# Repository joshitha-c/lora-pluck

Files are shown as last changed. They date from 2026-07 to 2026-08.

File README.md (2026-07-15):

# LoRa RP2040 Development Board

A custom-designed LoRa development board built in **KiCad**, combining the powerful **Raspberry Pi RP2040** microcontroller with the **Semtech SX1262 LoRa transceiver**. The board is designed for long-range wireless communication, rapid prototyping, IoT applications, and embedded systems development.
This development board is intended for long-range wireless communication and embedded IoT applications. The RP2040 acts as the main controller while the SX1262 provides LoRa connectivity for transmitting and receiving data over long distances.
---

## Features

- RP2040 dual-core ARM Cortex-M0+ microcontroller
- SX1262 LoRa transceiver (Sub-GHz communication)
- USB Type-C interface for programming and power
- External QSPI Flash memory
- 12 MHz crystal for RP2040
- 32 MHz crystal for SX1262
- RF matching network
- Antenna connector
- Reset and Boot buttons
- On-board voltage regulation
- Proper decoupling capacitors for stable operation
- Designed entirely in KiCad

---

## Main Components

| Component | Description |
|---|---|
| RP2040 | Main Microcontroller |
| SX1262 | LoRa Transceiver |
| W25Q Series Flash | External QSPI Flash Memory |
| USB-C Connector | Programming & Power |
| 12 MHz Crystal | RP2040 Clock |
| 32 MHz Crystal | SX1262 Clock |
| RF Matching Network | Impedance Matching |
| Antenna Connector | RF Output |

---

## Future Improvements

- OLED display support
- GPS module
- Battery charging circuit
- Li-ion battery connector
## Tools Used

- KiCad

schematic

pcb


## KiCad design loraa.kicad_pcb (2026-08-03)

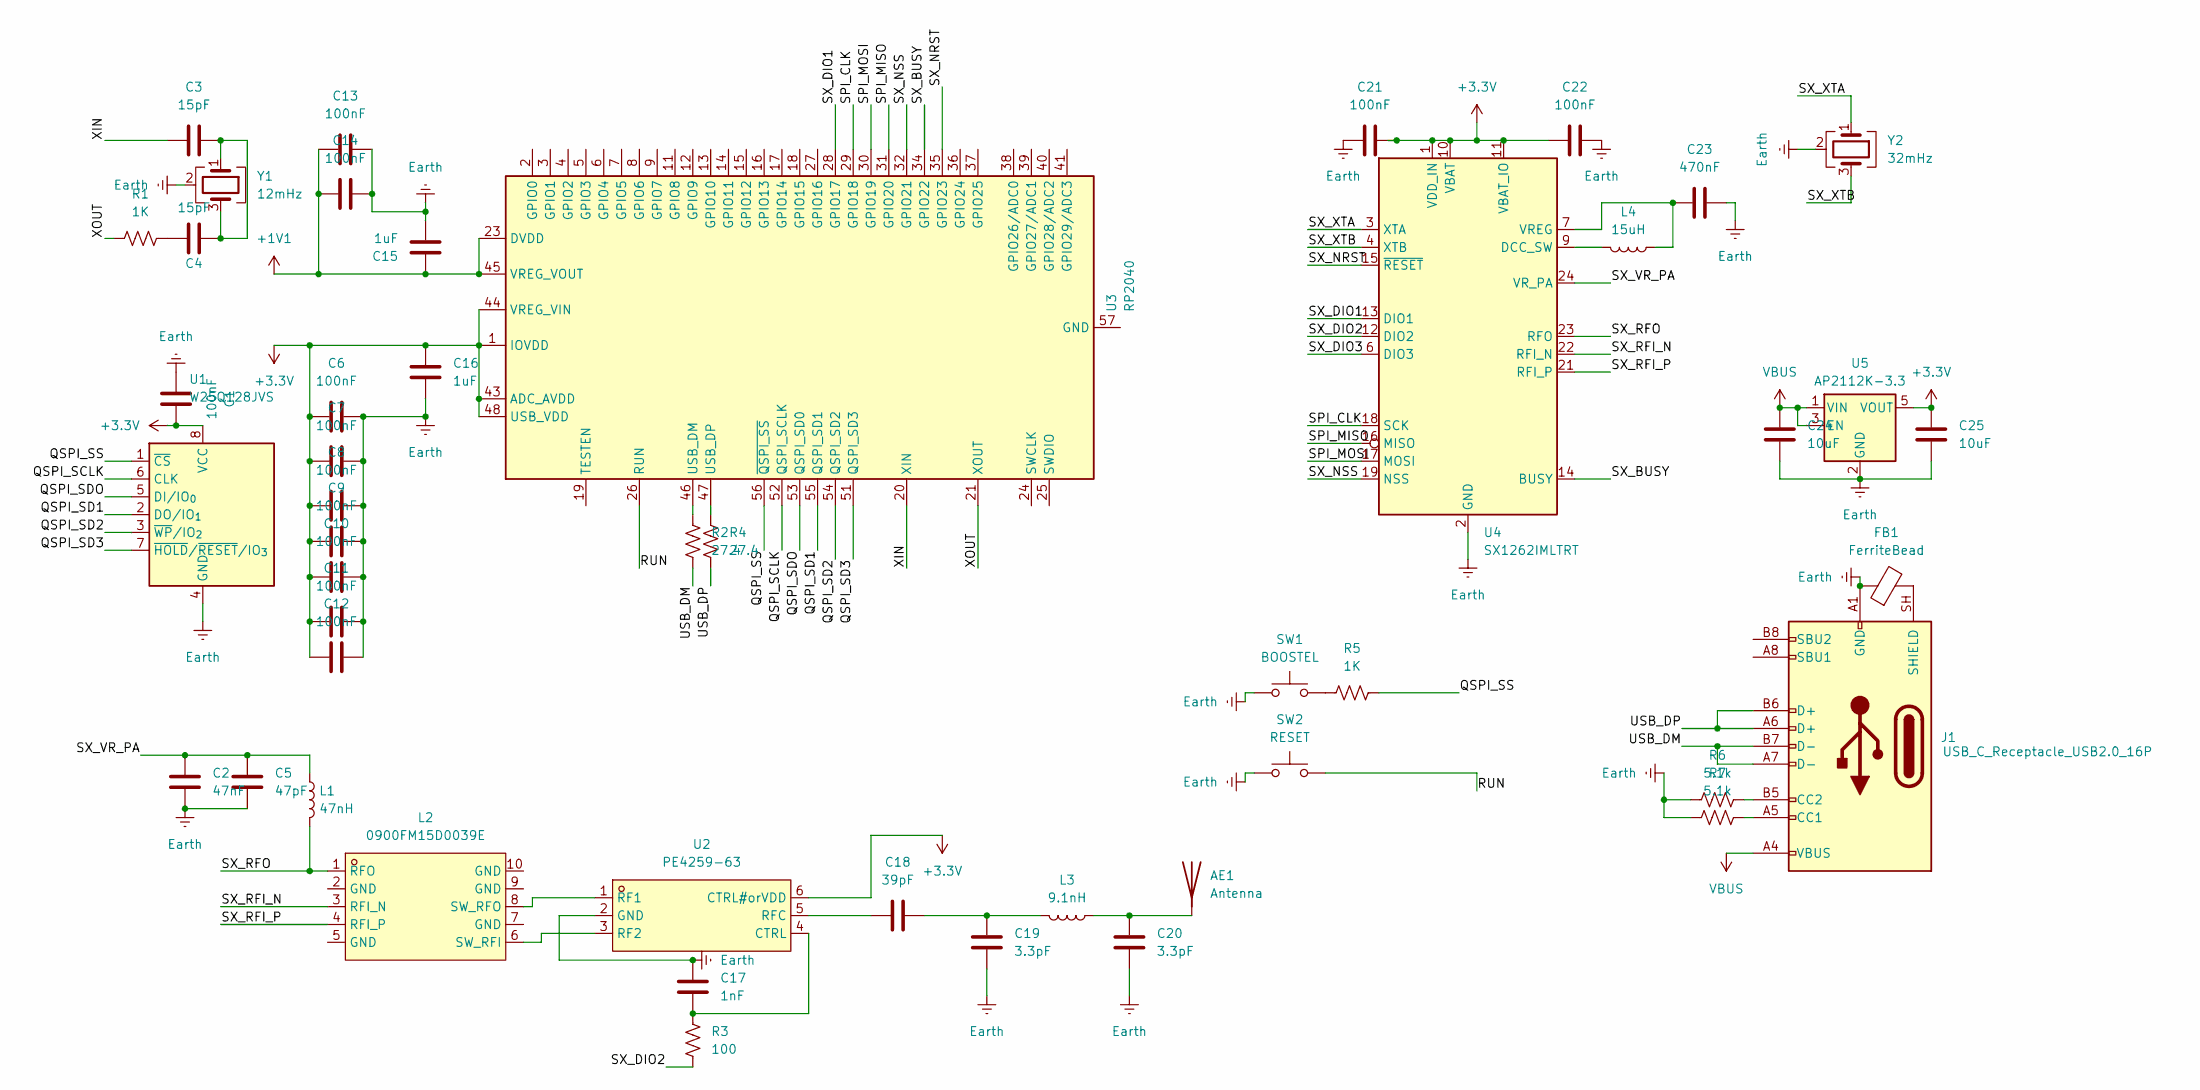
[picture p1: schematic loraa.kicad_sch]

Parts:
AE1: Antenna; PinSocket_1x01_P2.54mm_Vertical
C1, C6, C7, C8, C9, C10, C11, C12, C13, C14, C21, C22: 100nF; C_0402_1005Metric
C2: 47nF; C_0402_1005Metric
C3, C4: 15pF; C_0402_1005Metric
C5: 47pF; C_0402_1005Metric
C15, C16: 1uF; C_0402_1005Metric
C17: 1nF; C_0402_1005Metric
C18: 39pF; C_0402_1005Metric
C19, C20: 3.3pF; C_0402_1005Metric
C23: 470nF; C_0402_1005Metric
C24, C25: 10uF; C_0402_1005Metric
FB1: FerriteBead; L_0402_1005Metric
J1: USB_C_Receptacle_USB2.0_16P; USB_C_Receptacle_GCT_USB4105-xx-A_16P_TopMnt_Horizontal
L1: 47nH; L_0402_1005Metric
L2: 0900FM15D0039E; FILTER-SMD_10P-L2.0-W1.3-BL; MPN 0900FM15D0039E; LCSC Part C1513363
L3: 9.1nH; L_0402_1005Metric
L4: 15uH; L_0402_1005Metric
R1, R5: 1K; R_0402_1005Metric
R2, R4: 27.4; R_0402_1005Metric
R3: 100; R_0402_1005Metric
R6, R7: 5.1k; R_0402_1005Metric
SW1: BOOSTEL; SW_Tactile_SPST_NO_Straight_CK_PTS636Sx25SMTRLFS
SW2: RESET; SW_Tactile_SPST_NO_Straight_CK_PTS636Sx25SMTRLFS
U1: W25Q128JVS; SOIC-8_5.3x5.3mm_P1.27mm
U2: PE4259-63; SC-70-6_L2.2-W1.3-P0.65-LS2.1-BL; MPN PE4259-63; LCSC Part C470892
U3: RP2040; QFN-56-1EP_7x7mm_P0.4mm_EP3.2x3.2mm
U4: SX1262IMLTRT; QFN-24-1EP_4x4mm_P0.5mm_EP2.6x2.6mm
U5: AP2112K-3.3; SOT-23-5
Y1: 12mHz; Crystal_SMD_3225-4Pin_3.2x2.5mm
Y2: 32mHz; Crystal_SMD_Abracon_ABM8G-4Pin_3.2x2.5mm

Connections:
+1V1: C13.2, C14.2, C15.2, U3.23 (DVDD), U3.45 (VREG_VOUT), U3.50 (DVDD)
+3.3V: C1.1, C6.2, C7.2, C8.2, C9.2, C10.2, C11.2, C12.2, C16.2, C21.2, C22.1, C25.1, U1.8 (VCC), U2.6 (CTRL#orVDD), U3.1 (IOVDD), U3.10 (IOVDD), U3.22 (IOVDD), U3.33 (IOVDD), U3.42 (IOVDD), U3.43 (ADC_AVDD), U3.44 (VREG_VIN), U3.48 (USB_VDD), U3.49 (IOVDD), U4.1 (VDD_IN), U4.10 (VBAT), U4.11 (VBAT_IO), U5.5 (VOUT)
/QSPI_SCLK: U1.6 (CLK), U3.52 (QSPI_SCLK)
/QSPI_SD1: U1.2 (DO/IO_{1}), U3.55 (QSPI_SD1)
/QSPI_SD2: U1.3 (~WP/IO_{2}), U3.54 (QSPI_SD2)
/QSPI_SD3: U1.7 (~HOLD/~RESET/IO_{3}), U3.51 (QSPI_SD3)
/QSPI_SDO: U1.5 (DI/IO_{0}), U3.53 (QSPI_SD0)
/QSPI_SS: R5.2, U1.1 (~CS), U3.56 (~QSPI_SS)
/RUN: SW2.2, U3.26 (RUN)
/SPI_CLK: U3.29 (GPIO18), U4.18 (SCK)
/SPI_MISO: U3.31 (GPIO20), U4.16 (MISO)
/SPI_MOSI: U3.30 (GPIO19), U4.17 (MOSI)
/SX_BUSY: U3.34 (GPIO22), U4.14 (BUSY)
/SX_DIO1: U3.28 (GPIO17), U4.13 (DIO1)
/SX_DIO2: R3.2, U4.12 (DIO2)
/SX_DIO3: U4.6 (DIO3)
/SX_NRST: U3.35 (GPIO23), U4.15 (~RESET)
/SX_NSS: U3.32 (GPIO21), U4.19 (NSS)
/SX_RFI_N: L2.3 (RFI_N), U4.22 (RFI_N)
/SX_RFI_P: L2.4 (RFI_P), U4.21 (RFI_P)
/SX_RFO: L1.2, L2.1 (RFO), U4.23 (RFO)
/SX_VR_PA: C2.1, C5.1, L1.1, U4.24 (VR_PA)
/SX_XTA: U4.3 (XTA), Y2.1
/SX_XTB: U4.4 (XTB), Y2.3
/USB_DM: J1.A7 (D-), J1.B7 (D-), R2.2
/USB_DP: J1.A6 (D+), J1.B6 (D+), R4.1
/XIN: C3.1, U3.20 (XIN)
/XOUT: R1.1, U3.21 (XOUT)
Earth: C1.2, C2.2, C5.2, C6.1, C7.1, C8.1, C9.1, C10.1, C11.1, C12.1, C13.1, C14.1, C15.1, C16.1, C17.1, C19.2, C20.2, C21.1, C22.2, C23.2, C24.2, C25.2, FB1.1, J1.A1 (GND), J1.A12 (GND), J1.B1 (GND), J1.B12 (GND), R6.2, R7.2, SW1.1, SW2.1, U1.4 (GND), U2.2 (GND), U4.2 (GND), U4.5 (GND), U4.8 (GND), U4.20 (GND), U4.25 (GND), U5.2 (GND), Y1.2 (G), Y1.4 (G), Y2.2 (G), Y2.4 (G)
unnamed: AE1.1 (A_1), C20.1, L3.1
unnamed: C3.2, C4.2, Y1.1, Y1.3
unnamed: C4.1, R1.2
unnamed: C18.1, C19.1, L3.2
unnamed: J1.A5 (CC1), R7.1
unnamed: J1.B5 (CC2), R6.1
unnamed: FB1.2, J1.SH (SHIELD)
unnamed: L2.6 (SW_RFI), U2.3 (RF2)
unnamed: L2.8 (SW_RFO), U2.1 (RF1)
unnamed: R5.1, SW1.2
unnamed: C17.2, R3.1, U2.4 (CTRL)
unnamed: C18.2, U2.5 (RFC)
unnamed: R2.1, U3.46 (USB_DM)
unnamed: R4.2, U3.47 (USB_DP)
unnamed: L4.2, U4.9 (DCC_SW)
unnamed: C23.1, L4.1, U4.7 (VREG)
VBUS: C24.1, J1.A4 (VBUS), J1.A9 (VBUS), J1.B4 (VBUS), J1.B9 (VBUS), U5.1 (VIN), U5.3 (EN)

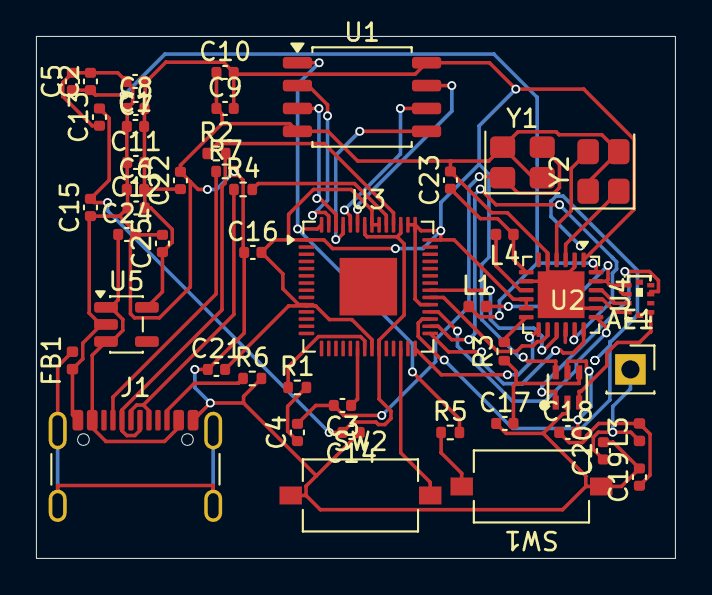
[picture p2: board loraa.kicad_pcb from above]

Board: 2 copper layers, 35.5 x 29.0 mm, 48 parts (0 on the bottom side), 45 nets.
